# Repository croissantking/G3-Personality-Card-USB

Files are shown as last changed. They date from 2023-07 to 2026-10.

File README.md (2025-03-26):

# Unlocking Hidden USB in the Beige G3

<b>Outline</b>
<br><br>
Many Beige G3s feature an unused footprint – on their Personality cards – for a single USB 1.1 port and supporting circuitry, similar to that found on period-correct USB PCI cards. This footprint appears on Version 2 of the Whisper and Wings A/V cards specifically, which shipped alongside the release of the AIO and updated motherboards. The rare Bordeaux DVD Video card also includes this feature and even supports dual ports.
<br><br>footprint
<br><br>
Interestingly, <a href="https://www.journaldulapin.com/2015/01/12/a-prototype-of-power-macintosh-g3-with-usb/">prototype Beige G3 machines exist</a> with onboard USB on their Personality card, but no production machines ever shipped with it installed. It's unclear whether Apple at one point planned for built-in USB on the Beige, or if the footprint was meant solely for development purposes.
<br><br>
As a longtime fan of the Beige G3, I was thrilled to discover this 'secret' feature. Given nobody else had tried to get it working (at least that I knew of) I decided to take on the challenge. I initially soldered in a CMD 0670 chip taken from a donor PCI card, then worked out the values of the capacitors and resistors that are required to get the USB circuitry working. Other key components included a 5V oscillator, a polyfuse and of course the USB port itself.
<br><br>
Here are a couple of modded cards:


<br><br>
<b>Modification</b>
<br><br>
Included in this repository are KiCad schematic files and BOMs for Whisper and Wings cards. The easiest way to get started is to follow the links below to order the Mouser projects I've created, then assemble your card using the BOM to help you. You will need a donor PCI card to take the USB controller chip from.
<br><br>
<table><thead>
  <tr>
    <th></th>
    <th>Schematic</th>
    <th>BOM</th>
    <th>Mouser Project</th>
  </tr></thead>
<tbody>
  <tr>
    <td>Whisper</td>
    <td><a href="https://github.com/croissantking/G3-Personality-Card-USB/blob/main/Whisper/Whisper%20USB%20V5.pdf" target="_blank" rel="noopener noreferrer">Whisper USB V5.pdf</a></td>
    <td><a href="https://github.com/croissantking/G3-Personality-Card-USB/blob/main/Whisper/Whisper%20USB%20BOM.csv" target="_blank" rel="noopener noreferrer">Whisper USB BOM.csv</a></td>
    <td><a href="https://www.mouser.co.uk/api/CrossDomain/GetContext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" target="_blank" rel="noopener noreferrer">CK's Whisper USB Mod</a></td>
  </tr>
  <tr>
    <td>Wings A/V</td>
    <td><a href="https://github.com/croissantking/G3-Personality-Card-USB/blob/main/Wings/Wings%20USB%20V3.pdf" target="_blank" rel="noopener noreferrer">Wings USB V3.pdf</a></td>
    <td><a href="https://github.com/croissantking/G3-Personality-Card-USB/blob/main/Wings/Wings%20USB%20BOM.csv" target="_blank" rel="noopener noreferrer">Wings USB BOM.csv</a></td>
    <td><a href="https://www.mouser.co.uk/api/CrossDomain/GetContext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" target="_blank" rel="noopener noreferrer">CK's Wings USB Mod</a></td>
  </tr>
</tbody></table>
<br>
You can install either a CMD 0670B-400 or an OPTi FireLink 82C861 chip. To use the Firelink, a small bodge is required when populating the board: PWRFLT1 must be tied to +5V. This can be achieved by locating the IC footprint for U9 (Whisper) or U19 (Wings A/V) and bridging pins 15 and 16 with a 10K resistor. The Firelink will fail to initialize if PWRFLT1 is left floating, which is not an issue with the 0670.
<br><br>

<br><br>
One of the more difficult tasks of the mod is creating an opening on the metal backplate to allow USB devices to plug in. My method is to mark out the opening and then stitch-drill and file from the inside.
<br><br>

<br><br>
So far, testing has shown the USB interface to be fully functional and reliable under Mac OS 9.2.2 and Mac OS X 10.2.8. It's seen as a PCI card in slot 'PERCH' and therefore relies on the same drivers as a traditional USB OHCI PCI card would.
<br><br>

<br><br>
<b>Startup Circuit</b>
<br><br>
A startup circuit exists as part of the USB footprint. It's optional, but if populated you will be able to start up your Beige G3 with the power key on an Apple USB keyboard. It's a really neat feature!<br><br>
<b>Power Supply – Fuse or Circuit Breaker?</b>
<br><br>
A USB port provides a +5V power supply to connected devices, which must be protected from overcurrent. The footprint allows for either a fuse (simpler, cheaper) or a UCC3912 electronic circuit breaker (more expensive, more reliable).  I opted for a resettable polyfuse but also experimented with the circuit breaker, though I couldn’t get it to fully work.
<br><br>
<b>Further Reading</b>
<br><br>
You can read about my journey here: https://68kmla.org/bb/index.php?threads/getting-g3-whisper-perch-usb-working.43681/
<br><br>
Hackaday also wrote an article about this project: https://hackaday.com/2023/04/01/apple-never-gave-them-usb-now-theyre-getting-it-for-themselves/
<br><br>
<b>Future goals</b>
<br><br>
– Get the the UCC3912 circuit breaker section working.<br>
– Draw up schematics for a Bordeaux card with an option for dual ports.
<br><br>
<b>Acknowledgements</b>
<br><br>
Thanks to 68kMLA's @phipli for his help in working out values of key components on the USB interface when I was still very new at this. Without support, I might not have got this off the ground.
<br><br><br>
<b>Peter Baran (@croissantking)</b>

<br><br>
--
<b>Update History</b>
<br><br>
24/5/2023 Uploaded schematic Rev 1, PDF and BOM.
<br><br>
12/7/2023 Updated schematic to Rev 2. Corrected some minor errors and made it clearer where the different circuits are.
<br><br>
3/7/2024 Updated the readme to explain what's needed to get the Firelink chip to work.
<br><br>
21/7/2024 Updated the Whisper schematic to V3, which includes layout improvements as well as worked out values for the Unitrode and power-on circuits, although they are not yet tested. Also uploaded a brand new Wings V1 schematic. Updated the readme accordingly.
<br><br>
25/7/2024 Uploaded Whisper V4 and Wings V2 schematics, which includes corrections to the startup circuit, now tested and working. 
<br><br>
28/7/2024 Added a new USB BOM for the Wings card, and startup circuit BOMs for both cards. Added links to Mouser projects in this readme.
<br><br>
8/3/2025 Combined BOMs and Mouser carts for base mod and startup circuits. Updated the Readme with a couple of new photos and a table which makes it easier to locate all the relevant files. Updated the schematics to make it clear that the Glue Logic section should not be populated.

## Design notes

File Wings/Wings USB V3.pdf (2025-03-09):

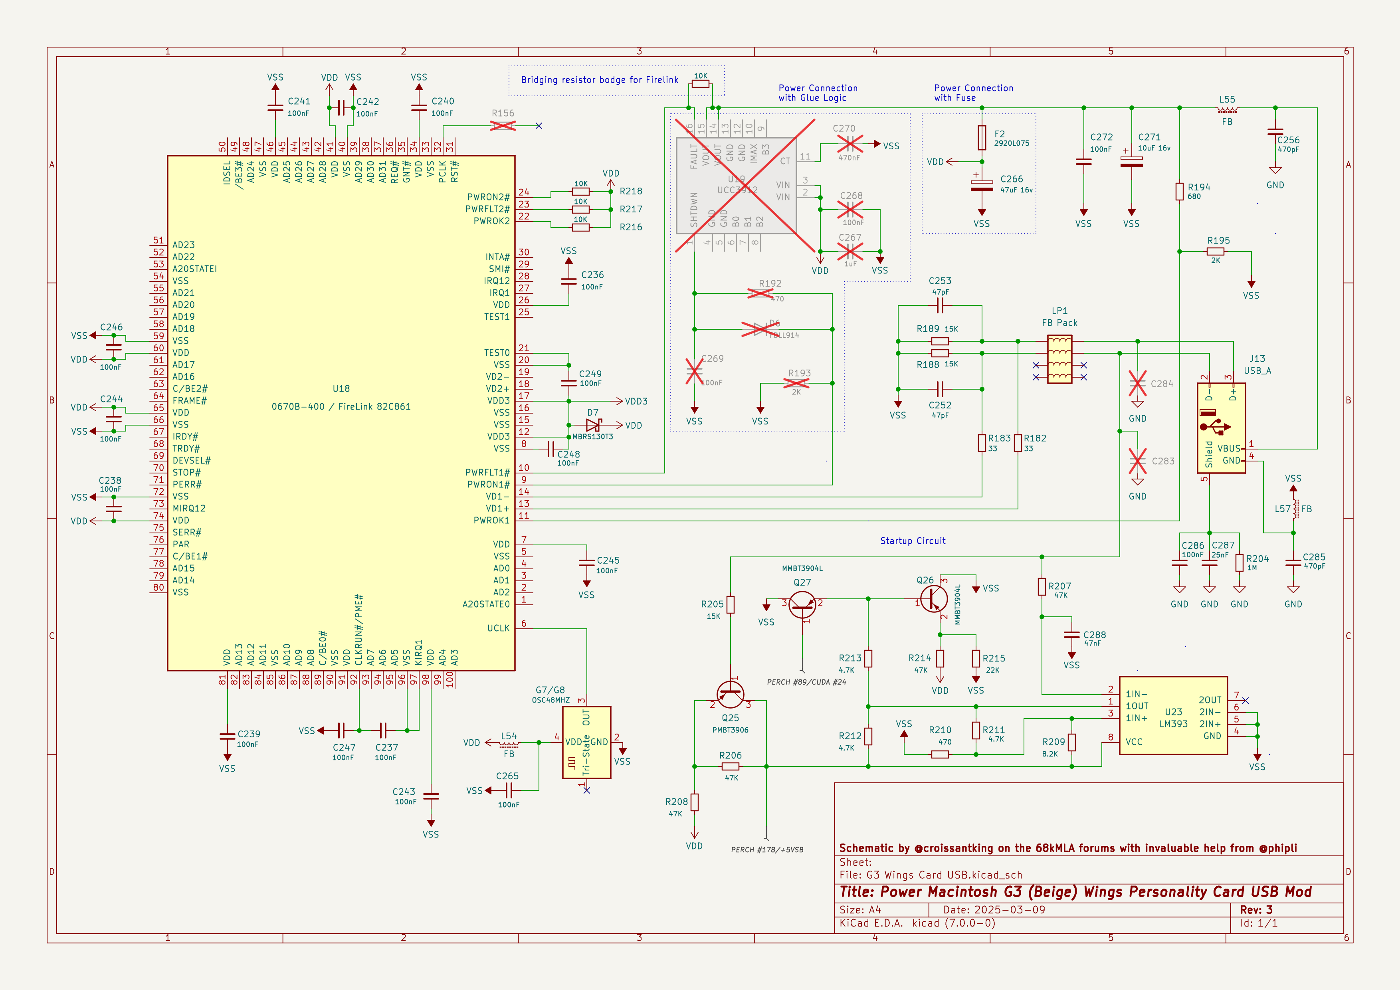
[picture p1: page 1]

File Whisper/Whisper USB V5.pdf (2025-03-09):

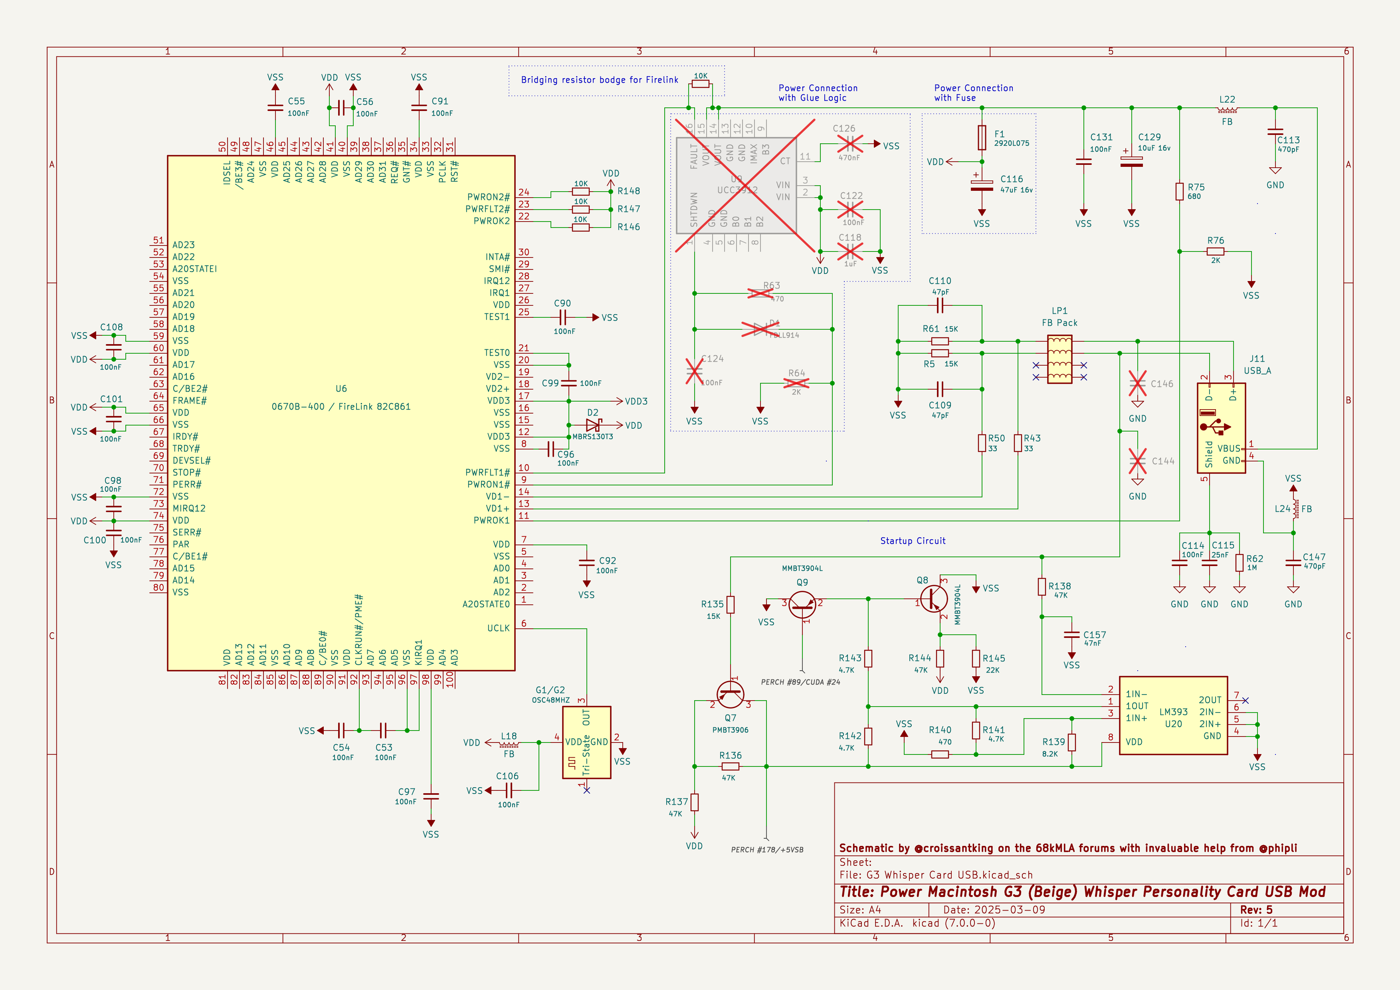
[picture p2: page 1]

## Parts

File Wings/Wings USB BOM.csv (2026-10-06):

Item | Qty | Reference(s) | Value | Size (Imperial) | Mfr P/N | Mouser URL
Capacitor | 16 | C236, C237, C238, C239, C240, C241, C242, C243, C244, C245, C246, C247, C248, C249, C265, C272 | 0.1uF | 0805 | 08055C104JAT2A | https://mou.sr/3LFR1Bc
Capacitor | 1 | C286 | 0.1uF | 0603 | 06035G104ZAT2A | https://mou.sr/44embap
Capacitor | 2 | C252, C253 | 47pF | 0603 | 06035A470JAT2A | https://mou.sr/3XnkNjh
Capacitor | 2 | C256, C285 | 470pF | 0603 | 06035A471JAT2A | https://mou.sr/42VHwnP
Capacitor | 1 | C287 | 25nF | 0603 | GRM1887U1A243JA01D | https://mou.sr/43SleED
Polarised Capacitor | 1 | C266 | 47uF 16V | L 6mm, Dia 6mm | 865230343004 | https://mou.sr/43SeaYH
Polarised Capacitor | 1 | C271 | 10uF 16V | L 6mm, Dia 4mm | 865230340001 | https://mou.sr/3qVU6Go
Fuse | 1 | F2 | 750mA Hold, 1.5A Trip | 2920 | 2920L075DR | https://mou.sr/4howH4S
Oscillator | 1 | G7/G8 | 48MHZ 5V | 7 x 5mm | LFSPXO019884REEL | https://mou.sr/3Podjuu
USB Port | 1 | J13 |  |  | 73725-01A0BLF | https://mou.sr/3rba3Zz
Ferrite Bead | 1 | L54 | 120 Ohms, 4A, 30mOhms | 1206 | HI1206P121R-10 | https://mou.sr/46vXDMo
Ferrite Bead | 2 | L55, L57 | 120 Ohms, 3A, 30mOhms | 0805 | BLM21PG121SN1D | https://mou.sr/3Xjtf2V
CMC | 1 | LP1 (Note: there are 4 sets of pads but we only need to bridge the top 2) |  | 1206 | DLW31SN900SQ2L | https://mou.sr/49yIBY6
Resistor | 2 | R188, R189 | 15K | 0805 | CR0805-JW-153ELF | https://mou.sr/3YiDvLD
Resistor | 2 | R182, R183 | 33 | 0805 | RC0805FR-0733RL | https://mou.sr/4zih0pg
Resistor | 1 | R204 | 1M | 0603 | RC0603FR-071ML | https://mou.sr/3XqpfxW
Resistor | 1 | OptiBodge | 10K | 0603 | AC0603JR-1310KL | https://mou.sr/42UXSNk
Resistor | 3 | R216, R217, R218 | 10K | 0805 | RC0805FR-0710KL | https://mou.sr/3CCjgfT
Resistor | 1 | R194 | 680 | 0805 | RC0805FR-13680RL | https://mou.sr/3DgQXYl
Resistor | 1 | R195 | 2K | 0805 | RC0805FR-7W2KL | https://mou.sr/3DfO0Hz
USB IC | 1 | U18 | 0670B-400 or 82C861 | LQFP-100
Schottky Diode | 1 | D7 | 1A If, 600mV Vf, 30V Vrrm | DO-214AA | MBRS130T3G | https://mou.sr/4he58uV
Capacitor | 1 | C288 | 47nF | 0603 | 06035D473KAT2A | https://mou.sr/4c1Fkjk
Transistor | 2 | Q26, Q27 | NPN | SOT-23-3 | MMBT3904-T | https://mou.sr/46mip0E
Transistor | 1 | Q25 | PNP | SOT-23-3 | PMBT3906,215 | https://mou.sr/3YtByMa
Resistor | 4 | R206, R207, R208, R214 | 47K | 0603 | AF0603FR-0747KL | https://mou.sr/3yg4UTL
Resistor | 1 | R215 | 22K | 0603 | CRCW060322K0FKEBC | https://mou.sr/3ycOOKF
Resistor | 1 | R205 | 15K | 0603 | RC0603FR-0715KP | https://mou.sr/3WE0xeG
Resistor | 1 | R209 | 8.2K | 0603 | RC0603JR-138K2L | https://mou.sr/46luQtP
Resistor | 3 | R211, R212, R213 | 4.7K | 0603 | RMC1/16K4701FTP | https://mou.sr/46qHLKN
Resistor | 1 | R210 | 470 | 0603 | SFR03EZPJ471 | https://mou.sr/3WkUL05
Comparator IC | 1 | U23 | LM393 | SOIC | LM393DT | https://mou.sr/3yd6IwT

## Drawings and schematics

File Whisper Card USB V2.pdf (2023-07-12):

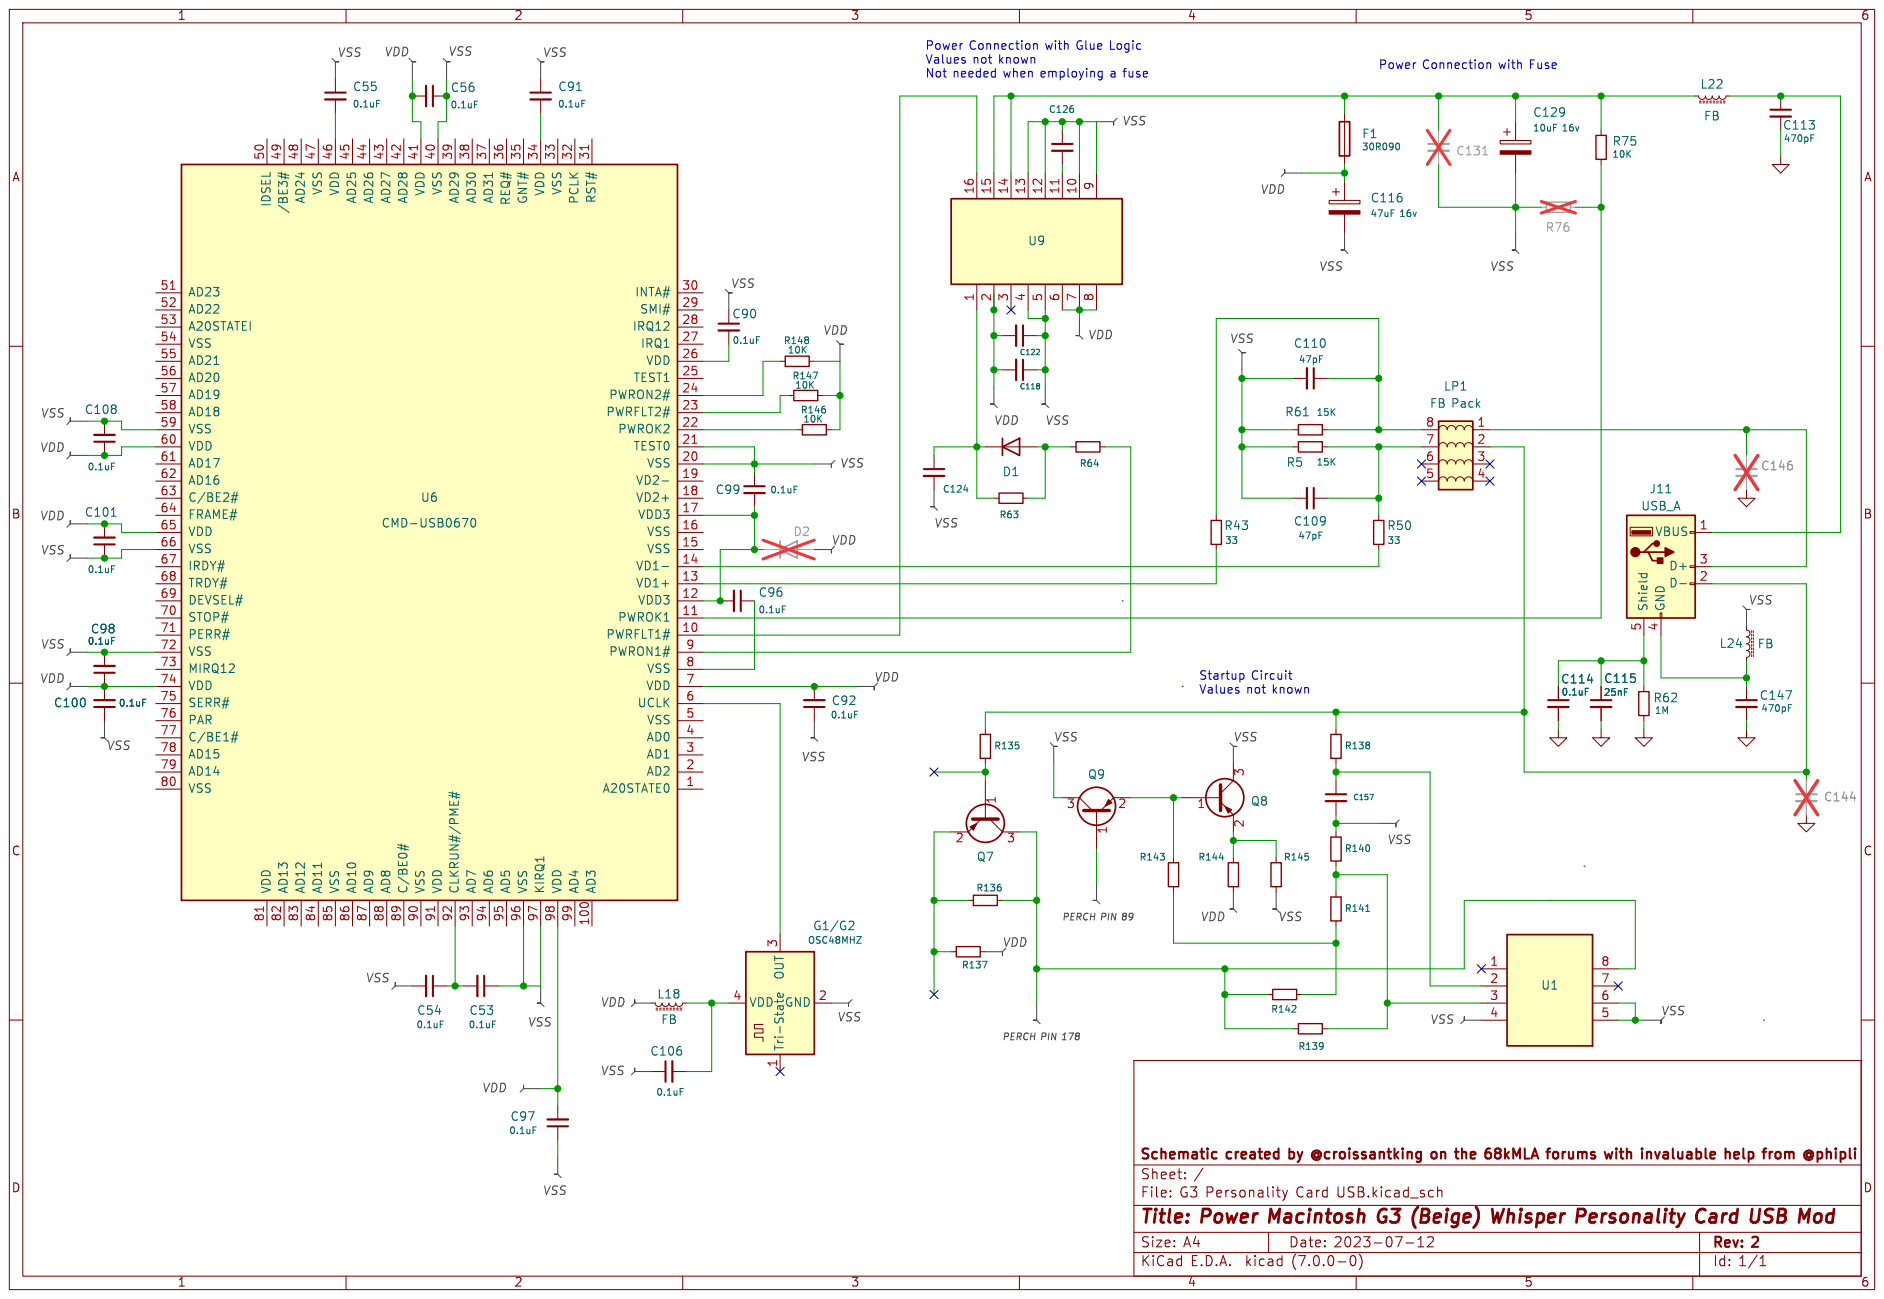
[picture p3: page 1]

Startup Circuit Values not known

Id: 1/1 Title: Power Macintosh G3 (Beige) Whisper Personality Card USB Mod

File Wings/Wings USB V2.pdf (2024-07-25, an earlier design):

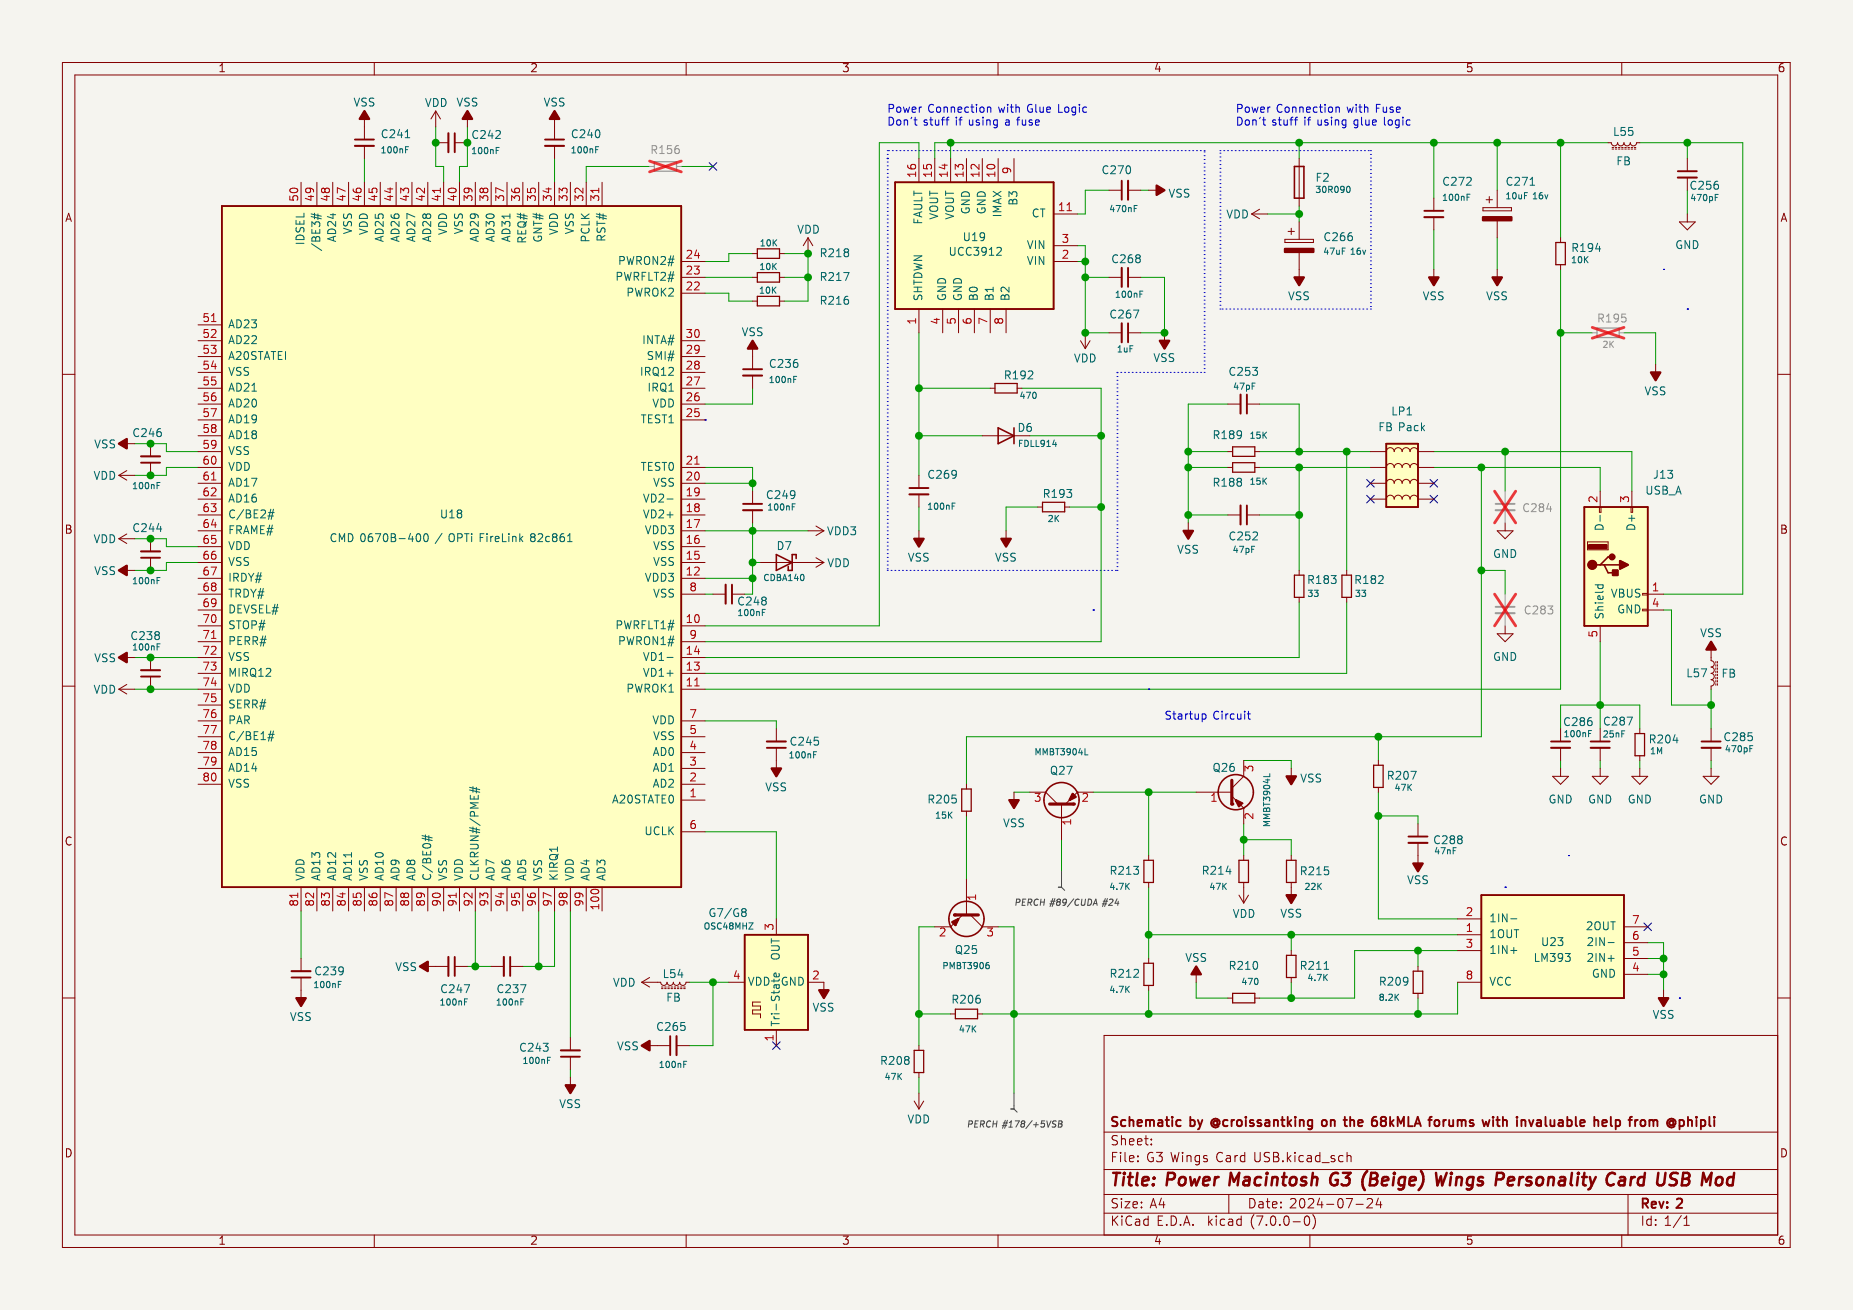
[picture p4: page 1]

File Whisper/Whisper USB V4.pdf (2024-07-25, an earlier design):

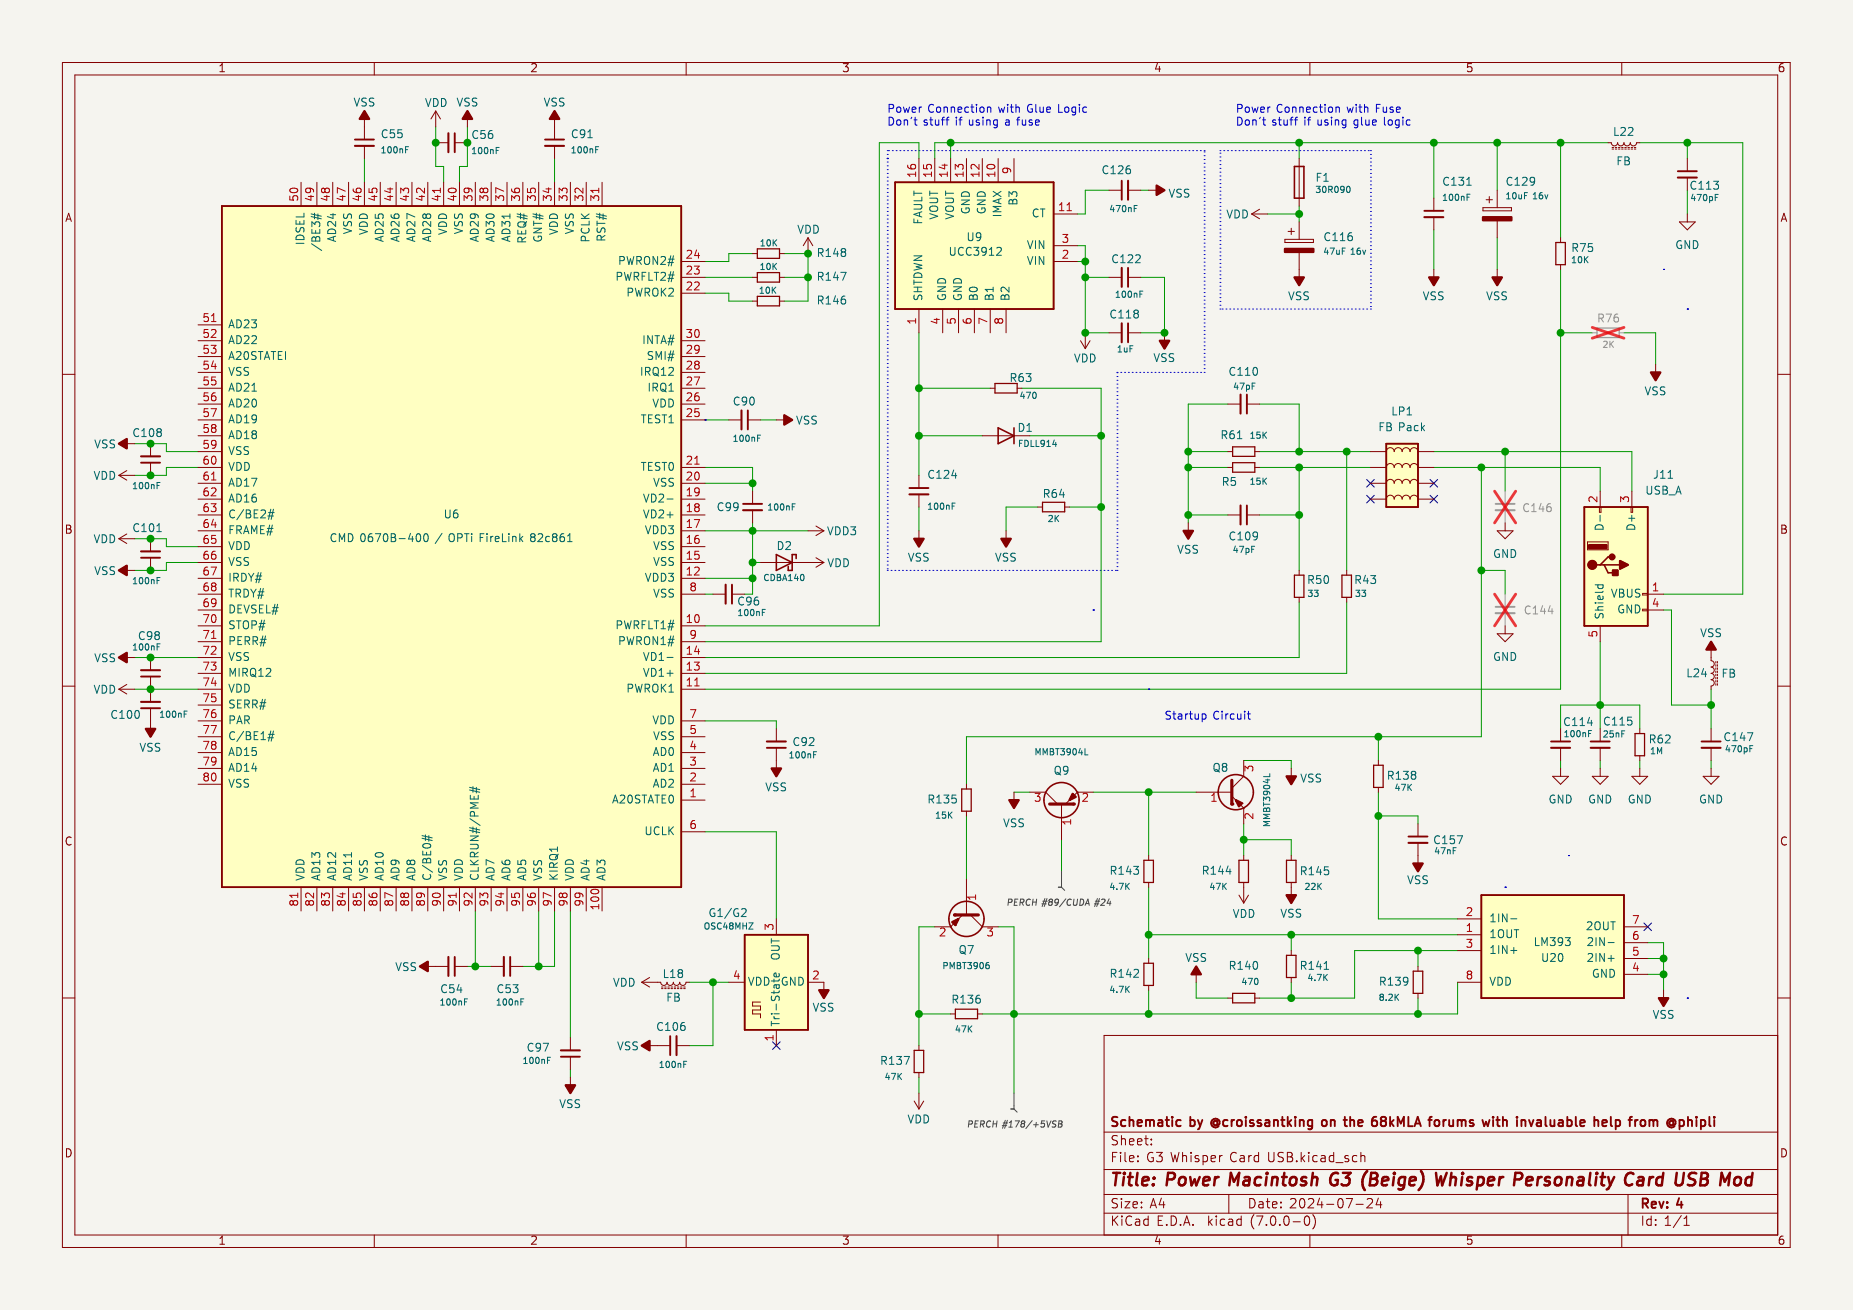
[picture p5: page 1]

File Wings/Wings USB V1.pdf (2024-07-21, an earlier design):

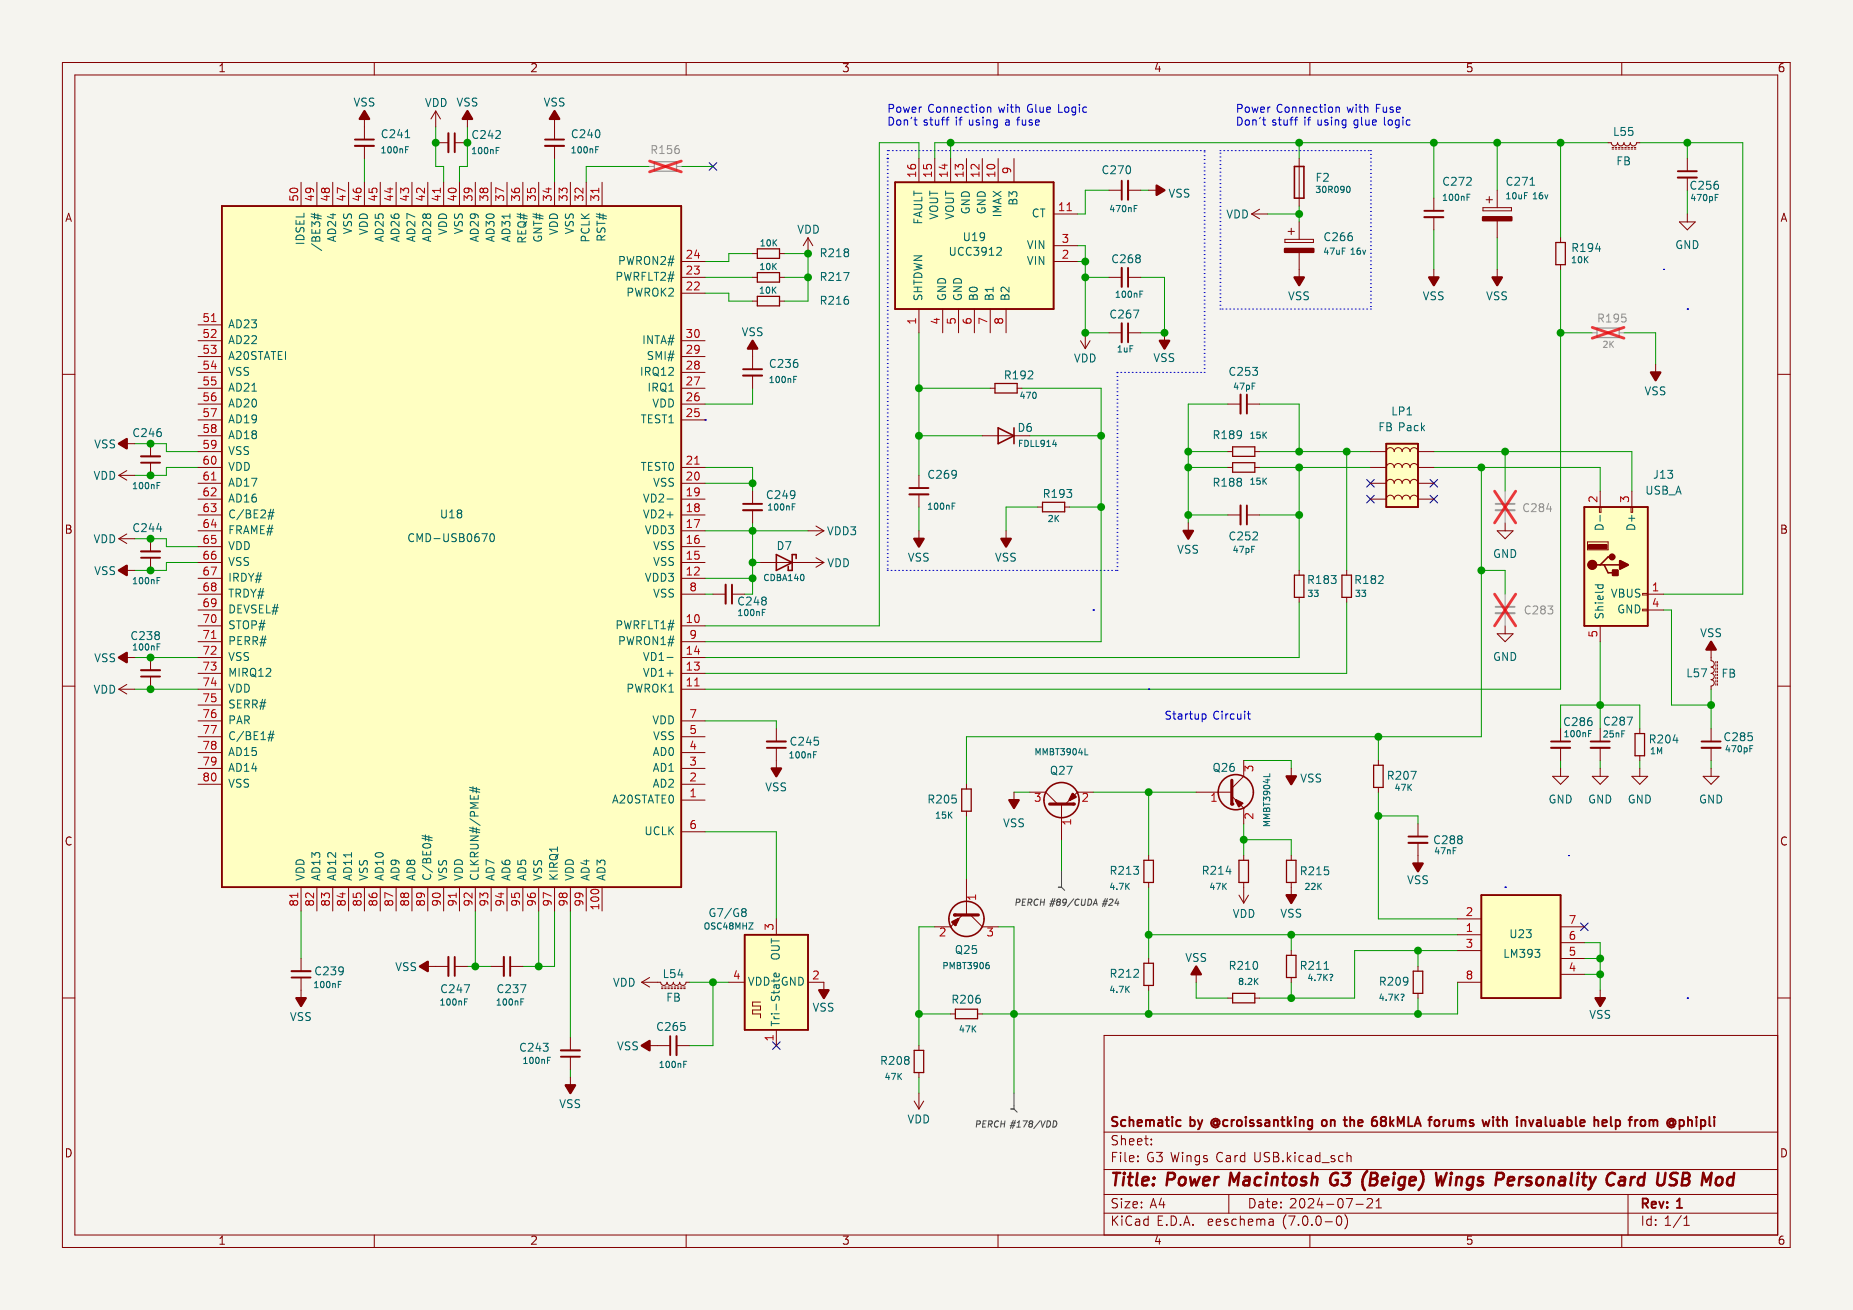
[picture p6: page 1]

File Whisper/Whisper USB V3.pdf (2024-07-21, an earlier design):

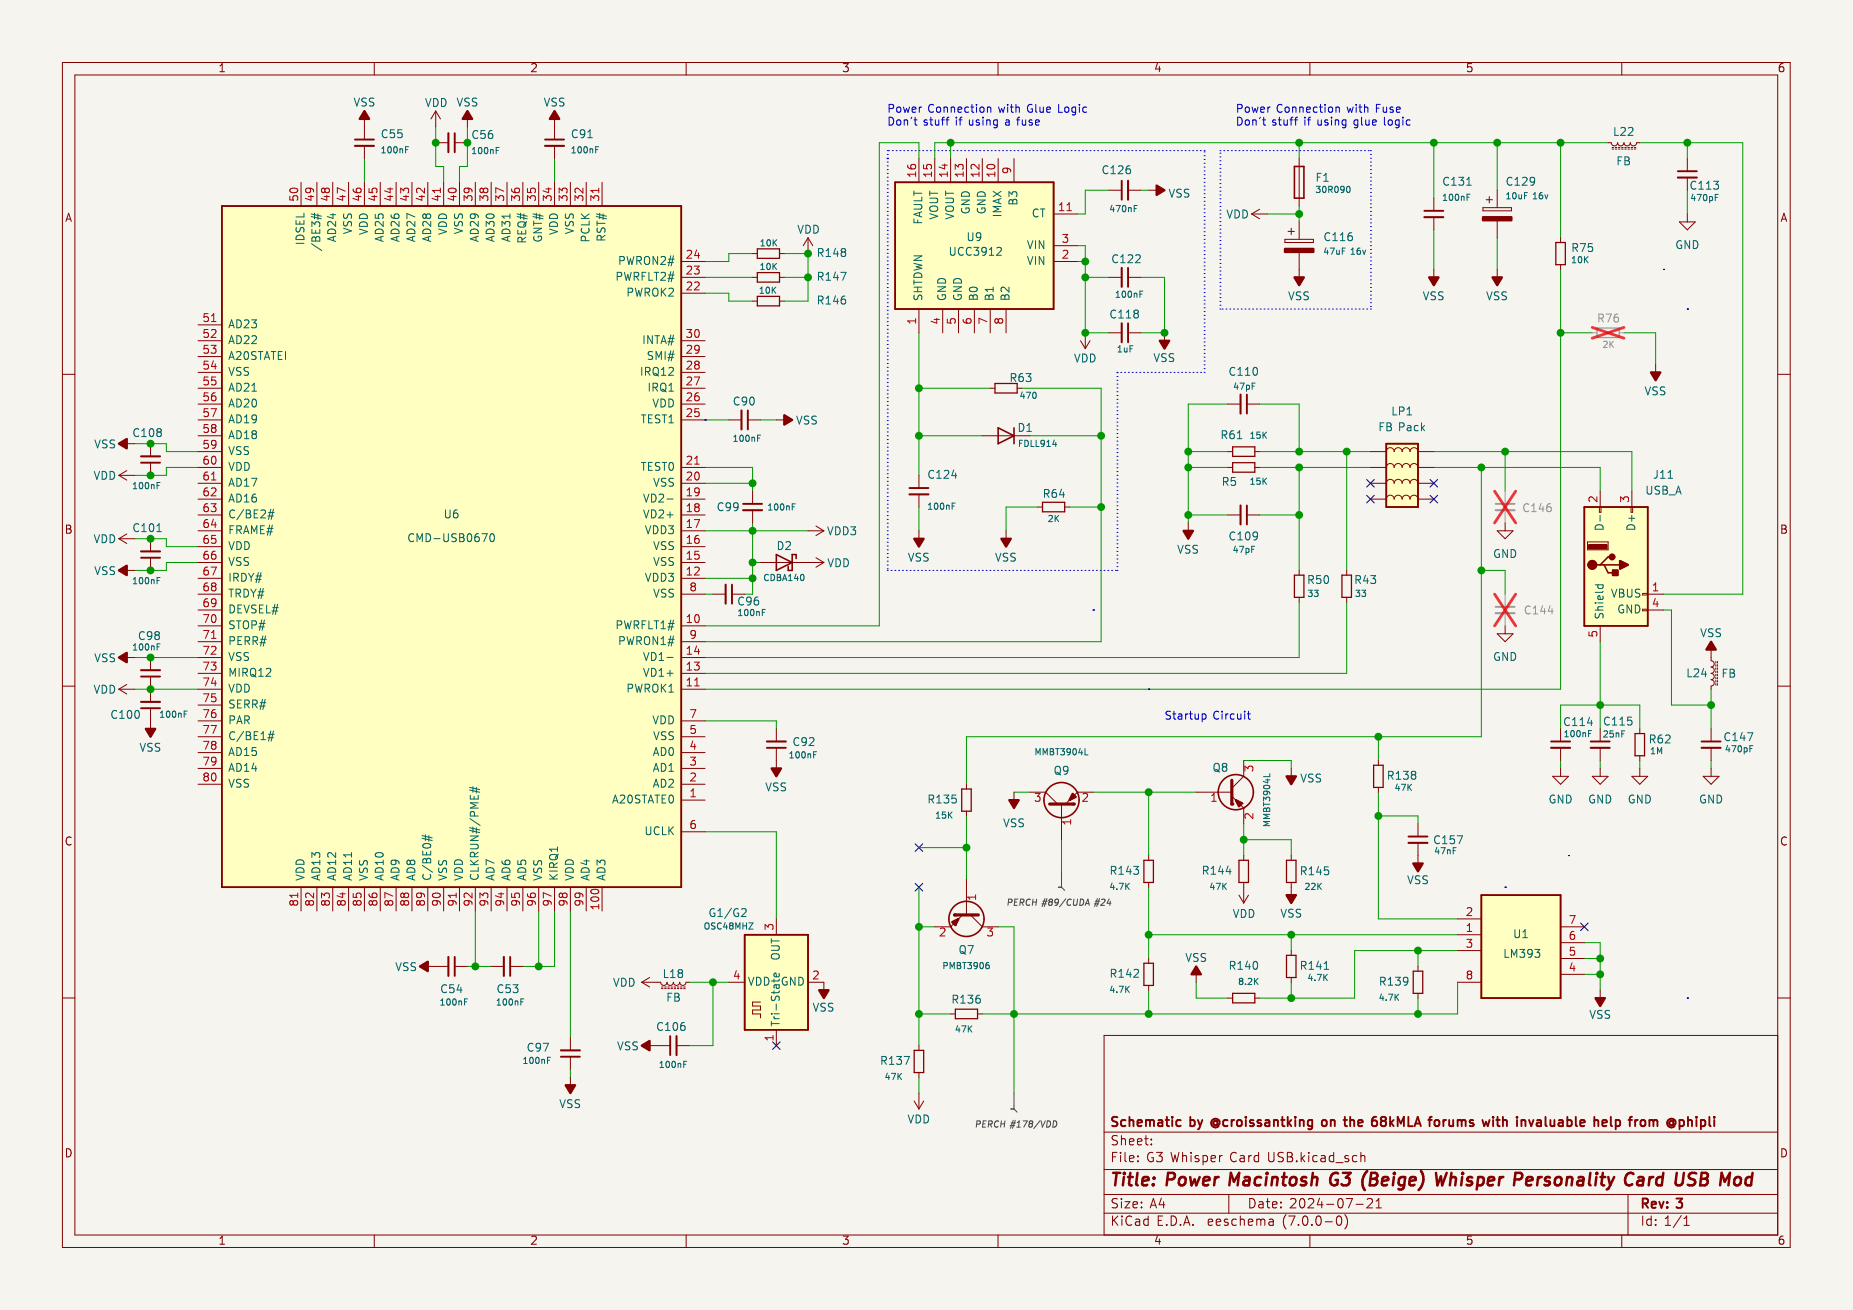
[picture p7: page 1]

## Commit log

2023-05-24 Rename G3 Personality Card USB.csv to G3 Personality Card USB BOM.csv
    [G3 Personality Card USB BOM.csv]
2023-06-19 Update G3 Personality Card USB BOM.csv
    [G3 Personality Card USB BOM.csv]
2024-07-03 Rename G3 Personality Card USB BOM.csv to Whisper USB BOM.csv
    Renamed to differentiate from the Wings BOM.
    [Whisper USB BOM.csv]
2024-07-03 Create Wings USB BOM
    New BOM to split off from Whisper.
2024-07-03 Rename Wings USB BOM to Wings USB BOM.csv
    [Wings USB BOM.csv]
2024-07-03 Rename G3 Personality Card USB.kicad_sch to Whisper Card USB.kicad_sch
    [Whisper Card USB.kicad_sch]
2024-07-03 Update Wings USB BOM.csv
    [Wings USB BOM.csv]
2024-07-21 Rename Whisper Card USB.kicad_sch to Whisper/Whisper Card USB.kicad_sch
    [Whisper Card USB.kicad_sch]
2024-07-21 Rename Whisper/Whisper Card USB.kicad_sch to Whisper Card USB.kicad_sch
    [Whisper Card USB.kicad_sch]
2024-07-21 Rename Whisper Card USB.kicad_sch to Whisper Card USB V2.kicad_sch
    [Whisper Card USB V2.kicad_sch]
2024-07-21 Rename Whisper Card USB V2.kicad_sch to Whisper/Whisper Card USB V2.kicad_sch
    [Whisper Card USB V2.kicad_sch]
2024-07-21 Rename Whisper/Whisper Card USB V2.kicad_sch to Whisper/Old/Whisper Card USB V2.kicad_sch
    [Whisper Card USB V2.kicad_sch]
2024-07-21 Rename Whisper USB BOM.csv to Whisper/Whisper USB BOM.csv
    [Whisper USB BOM.csv]
2024-07-21 Rename G3 Whisper Card USB.kicad_sch to Whisper USB V3.kicad_sch
    [Whisper USB V3.kicad_sch]
2024-07-21 Rename Wings USB BOM.csv to Wings/Wings USB BOM.csv
    [Wings USB BOM.csv]
2024-07-21 Rename G3 Wings Card USB.kicad_sch to Wings USB V1.kicad_sch
    [Wings USB V1.kicad_sch]
2024-07-21 Rename G3 Wings Card USB.pdf to Wings USB V1.pdf
2024-07-21 Rename Rear bracket cutouts.JPG to Photos/Rear bracket cutouts.JPG
2024-07-21 Rename Populated cards.JPG to Wings/Populated cards.JPG
2024-07-21 Update Whisper USB BOM.csv
    [Whisper USB BOM.csv]
2024-07-24 Rename Whisper/Whisper USB V3.kicad_sch to Whisper/Old/Whisper USB V3.kicad_sch
    [Whisper USB V3.kicad_sch]
2024-07-24 Rename G3 Whisper Card USB.kicad_sch to Whisper USB V4.kicad_sch
    [Whisper USB V4.kicad_sch]
2024-07-24 Rename Whisper Card USB V2.kicad_sch to Whisper USB V2.kicad_sch
    [Whisper USB V2.kicad_sch]
2024-07-24 Rename Wings/Wings USB V1.pdf to Wings/Old/Wings USB V1.pdf
2024-07-24 Rename Wings/Wings USB V1.kicad_sch to Wings/Old/Wings USB V1.kicad_sch
    [Wings USB V1.kicad_sch]
2024-07-24 Rename G3 Wings Card USB.pdf to Wings USB V2.pdf
2024-07-24 Rename G3 Wings Card USB.kicad_sch to Wings USB V2.kicad_sch
    [Wings USB V2.kicad_sch]
2024-07-28 Create Startup Circuit.csv
    [Startup Circuit.csv]
2024-07-28 Update Startup Circuit.csv
    [Startup Circuit.csv]
2024-07-28 Rename Startup Circuit.csv to Wings Startup Circuit.csv
    [Wings Startup Circuit.csv]
2024-07-28 Rename Startup Circuit.csv to Whisper Startup Circuit.csv
    [Whisper Startup Circuit.csv]
2024-07-28 Update Whisper Startup Circuit.csv
    [Whisper Startup Circuit.csv]
2024-07-28 Update Wings Startup Circuit.csv
    [Wings Startup Circuit.csv]
2025-03-08 Update Whisper USB BOM.csv
    Moved startup mod items into this BOM
    [Whisper USB BOM.csv]
2025-03-08 Delete Whisper/Whisper Startup Circuit.csv
    Deleted because I moved all the items into the main BOM
    [Whisper Startup Circuit.csv]
2025-03-08 Update Wings USB BOM.csv
    Added startup items into this BOM
    [Wings USB BOM.csv]
2025-03-08 Update README.md
    Combined BOMs and Mouser carts for base mod and startup circuits. Updated the Readme with a couple of new photos and a table which makes it easier to locate all the relevant files.
2025-03-09 Rename Wings/Wings USB V2.pdf to Wings/Old/Wings USB V2.pdf
2025-03-09 Rename Whisper/Whisper USB V4.kicad_sch to Whisper/Old/Whisper USB V4.kicad_sch
    [Whisper USB V4.kicad_sch]
2025-03-09 Rename Wings/Wings USB V2.kicad_sch to Wings/Old/Wings USB V2.kicad_sch
    [Wings USB V2.kicad_sch]
2026-10-06 Update Whisper USB BOM.csv
    Changed Mouser P/Ns to Mfr P/Ns, so that parts can be more easily looked up on any supplier.
    [Whisper USB BOM.csv]
2026-10-06 Update Wings USB BOM.csv
    Changed Mouser P/N to Mfr P/N, to make cross supplier purchases easier.
    [Wings USB BOM.csv]
